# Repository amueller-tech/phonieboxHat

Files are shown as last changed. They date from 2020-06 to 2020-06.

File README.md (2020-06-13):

# phonieboxHat
A RaspberryPi Hat for the Phoniebox

Documentation: http://phoniebox.amueller.org

This is a KiCad project for a RaspberryPi Hat to build a Phoniebox, which
basically is a Jukebox for Kids (http://phoniebox.de/)

The PCB can be stacked to a RaspberryPi and offers interfaces connect Buttons,
LEDs, a I2C Display and an OnOffShim. 

Current version is: 0.3, release 2020-06-13

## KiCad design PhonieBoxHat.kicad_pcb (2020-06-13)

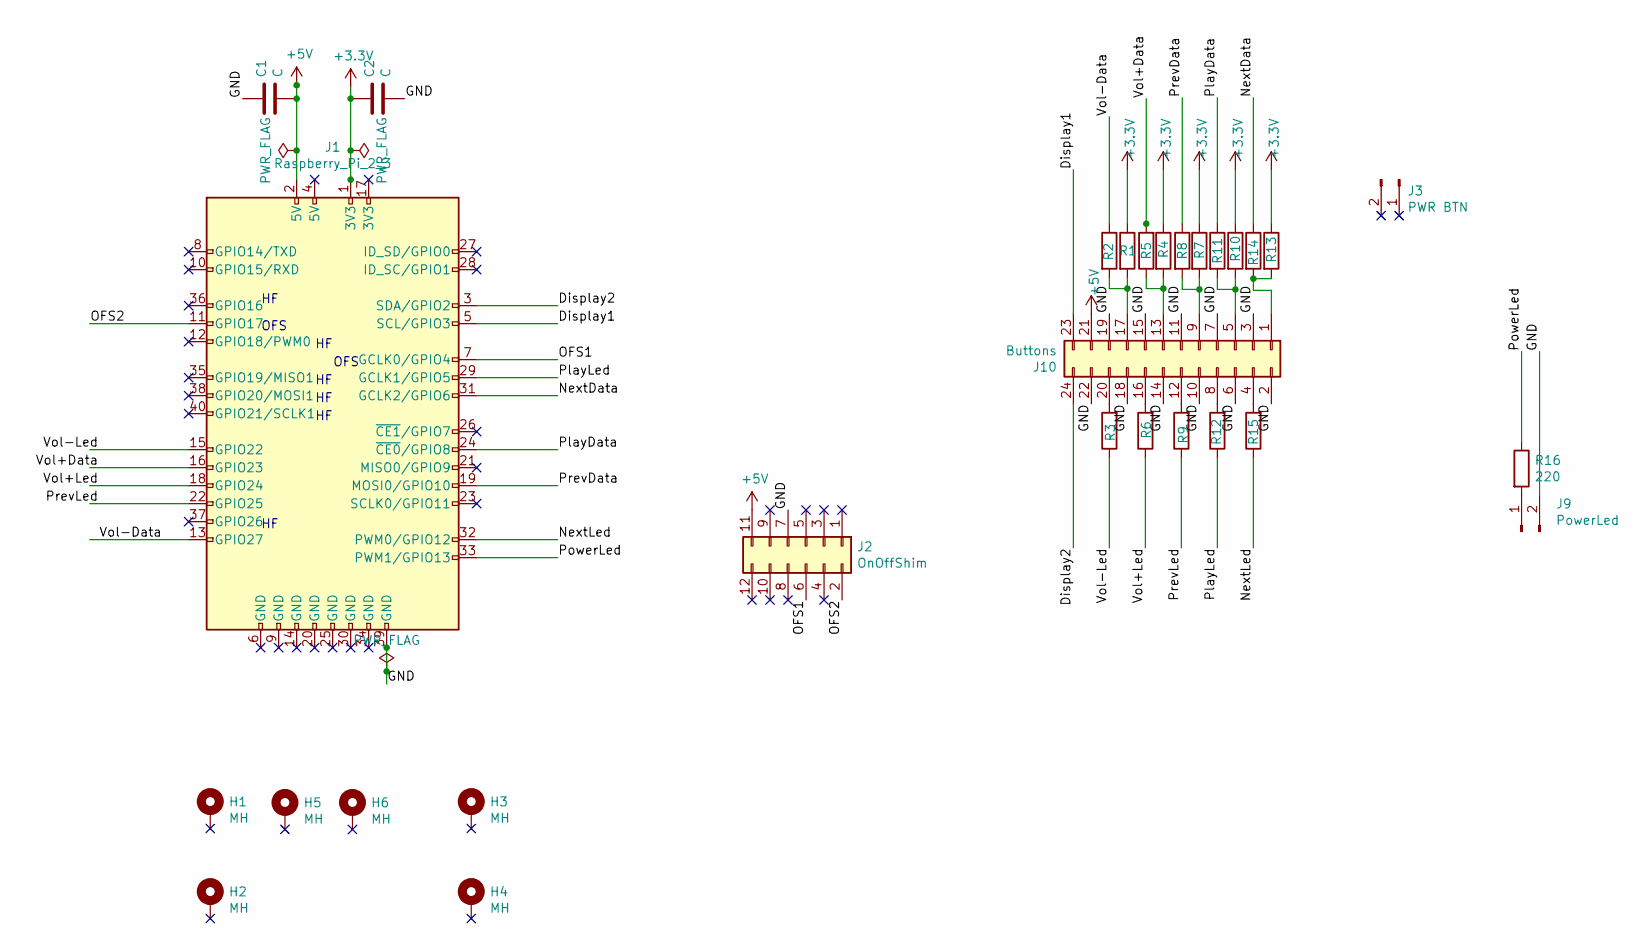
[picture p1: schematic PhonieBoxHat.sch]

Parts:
C1, C2: C; C_1206_3216Metric_Pad1.42x1.75mm_HandSolder
H1, H2, H3, H4, H5, H6: MH; MountingHole_3mm_Pad
J1: Raspberry_Pi_2_3; PinSocket_2x20_P2.54mm_Vertical
J2: OnOffShim; PinHeader_2x06_P2.54mm_Vertical
J3: PWR BTN; PinSocket_1x02_P2.54mm_Vertical
J9: PowerLed; PinHeader_1x02_P2.54mm_Horizontal
J10: Buttons; PinHeader_2x12_P2.54mm_Horizontal
R1, R4, R7, R10, R13: 10K; R_1206_3216Metric_Pad1.42x1.75mm_HandSolder
R2, R5, R8, R11, R14: 1K; R_1206_3216Metric_Pad1.42x1.75mm_HandSolder
R3, R6, R9, R12, R15, R16: 220; R_1206_3216Metric_Pad1.42x1.75mm_HandSolder

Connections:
+3V3: C2.1, J1.1 (3V3), R1.1, R4.1, R7.1, R10.1, R13.1
+5V: C1.2, J1.2 (5V), J2.11, J10.21
/Display1: J1.5 (SCL/GPIO3), J10.23
/Display2: J1.3 (SDA/GPIO2), J10.24
/GND: C1.1, C2.2, J1.39 (GND), J2.7, J9.2, J10.2, J10.3, J10.6, J10.7, J10.10, J10.11, J10.14, J10.15, J10.18, J10.19, J10.22
/NextData: J1.31 (GCLK2/GPIO6), R14.1
/NextLed: J1.32 (PWM0/GPIO12), R15.1
/OFS1: J1.7 (GCLK0/GPIO4), J2.6
/OFS2: J1.11 (GPIO17), J2.2
/PlayData: J1.24 (~CE0~/GPIO8), R11.1
/PlayLed: J1.29 (GCLK1/GPIO5), R12.1
/PowerLed: J1.33 (PWM1/GPIO13), R16.1
/PrevData: J1.19 (MOSI0/GPIO10), R8.1
/PrevLed: J1.22 (GPIO25), R9.1
/Vol+Data: J1.16 (GPIO23), R5.2
/Vol+Led: J1.18 (GPIO24), R6.1
/Vol-Data: J1.13 (GPIO27), R2.1
/Vol-Led: J1.15 (GPIO22), R3.1
unnamed: J9.1, R16.2
unnamed: J10.1, R13.2, R14.2
unnamed: J10.4, R15.2
unnamed: J10.5, R10.2, R11.2
unnamed: J10.8, R12.2
unnamed: J10.9, R7.2, R8.2
unnamed: J10.12, R9.2
unnamed: J10.13, R4.2, R5.1
unnamed: J10.16, R6.2
unnamed: J10.17, R1.2, R2.2
unnamed: J10.20, R3.2

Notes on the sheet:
OFS

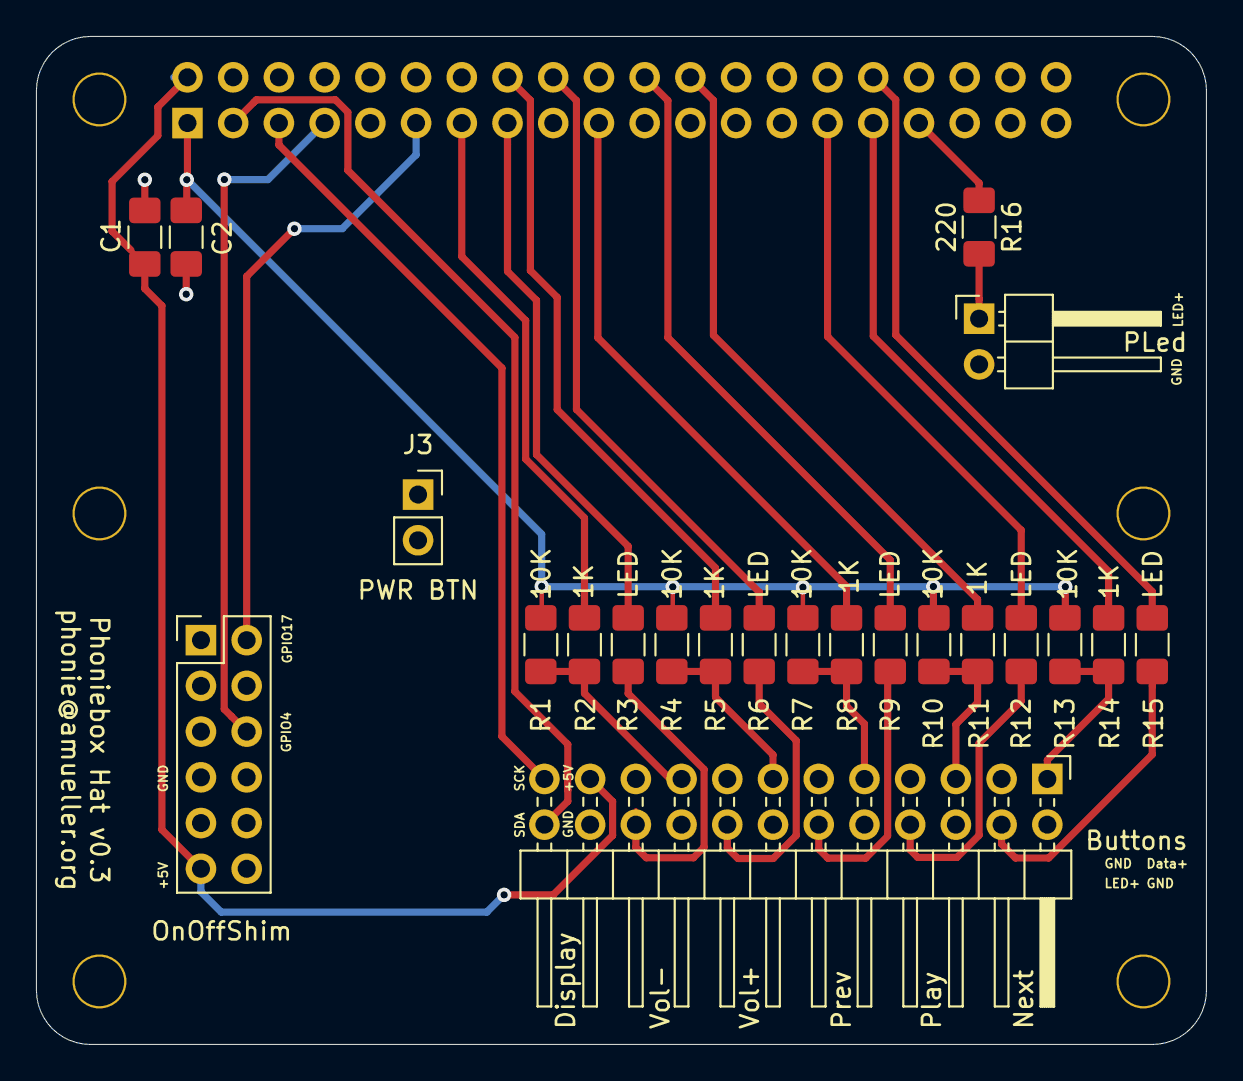
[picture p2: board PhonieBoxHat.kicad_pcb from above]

Board: 2 copper layers, 65.0 x 56.0 mm, 29 parts (1 on the bottom side), 29 nets.

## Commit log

2019-11-08 Initial PhonieBoxHat Version
    This is the initial commit of the PhonieBoxHat Version 0.2 that
    I successfully used to build up my Phoniebox as documented here: https://phoniebox.amueller.org
    [PhonieBoxHat.kicad_pcb, PhonieBoxHat.sch]
2020-06-13 v0.3
    New version of the PCB to integrate the OnOffShim
    [PhonieBox3.kicad_pcb, PhonieBox3.sch, PhonieBoxHat.kicad_pcb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]
2022-04-15 directory cleanup of old version
    [PhonieBox3.kicad_pcb, PhonieBox3.sch, noname.kicad_pcb]
